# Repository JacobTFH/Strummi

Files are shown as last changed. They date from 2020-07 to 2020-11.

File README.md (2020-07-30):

# Strummi

## About

The _Strummi_ is a guitar-based Accessible Digital Musical Instrument (ADMI) designed to make guitar playing more physically accessible while preserving the tactile and acoustic response of real guitar strings.
It was developed as part of my PhD research at Queen Mary University of London, with my co-researcher Robert Jack.

The Strummi runs on c++ on the [Bela](https://bela.io/) environment.

You can see videos of the Strummi and find out more about it's use on the [projects](https://jacobtfh.github.io/projects) page of [my website](https://jacobtfh.github.io)

## To do

- Add source code and design files to git repo
- Design GUI in p5.js for changing tunings and chord voicings
- Make Instructables for DMLab AMIC
- Test with cycfi nu pickups
- Improvements to sound: body resonance / pickup modelling etc.

## License

<br />This work is licensed under a <a rel="license" href="http://creativecommons.org/licenses/by-nc/3.0/">Creative Commons Attribution-NonCommercial 3.0 Unported License</a>.

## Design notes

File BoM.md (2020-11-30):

*Enclosure:*
- 5mm plywood for lid and sides of enclosure
  - <2 sheets required
- 3mm plywood for base and binding
  - <1 sheet required
- 3mm acrylic for faceplate and connections panel
- 6x 30mm M3 hex spacers
- 12 x 30mm M3 bolts

*Strings*
- 6x zither pins
- Zither tuning key
- Guitar strings
  - 2x .40 gauge bass guitar string works well
- 6x string ferrules
- 4x cable crimps
- Felt for bridge

*Pickups*
- 6x 15mm piezo disc pickup
- 5mm and 3mm ply
  - use leftover from enclosure material
- 6mm foam plastazote
  - <1 sheet required

*Bela*
- Bela mini
- Custom PCB (see design files)
- 9-way male molex connector
- 12-way male molex connector
- 3-way male molex connector
- 3-way female header pins
- 10-way male header pin (long, for analog pins)
- ~16 male header pin (normal size, for digital pins)
  - we only need a few digital GPIO pins, so there's no need to populate the entire PCB. but it's useful to have a few extra for strain relief
- Bela audio connector (comes with Bela mini kit)
- Micro-USB to micro-USB panel mount connector

*Buttons*
- 2x 2x2 silicon push button pads
- 2x 2x2 push button PCB
- 6x M3 bolts
-

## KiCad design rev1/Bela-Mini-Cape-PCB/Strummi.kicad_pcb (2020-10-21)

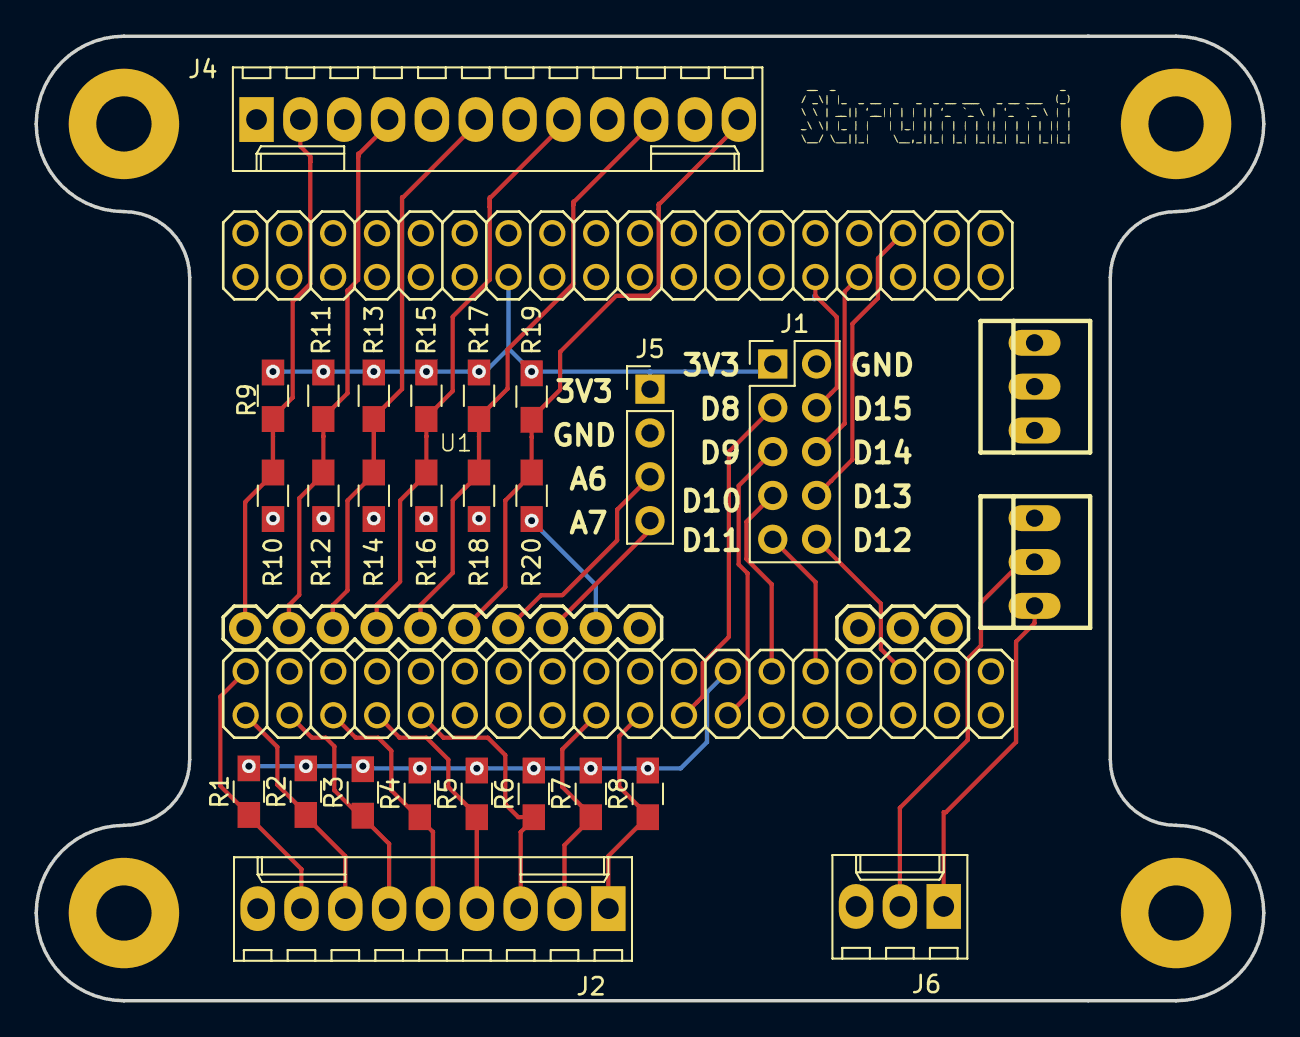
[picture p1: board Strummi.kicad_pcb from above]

Board: 2 copper layers, 71.1 x 55.9 mm, 26 parts (0 on the bottom side), 28 nets.

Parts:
J1: Conn_01x10_Female; Pin_Header_Straight_2x05_Pitch2.54mm
J2: Conn_01x09_Female; Molex_KK-6410-09_09x2.54mm_Straight
J4: Conn_01x12_Female; Molex_KK-6410-12_12x2.54mm_Straight
J5: Conn_01x04_Female; Pin_Header_Straight_1x04_Pitch2.54mm
J6: Conn_01x03_Female; Molex_KK-6410-03_03x2.54mm_Straight
R1, R2, R3, R4, R5, R6, R7, R8, R9, R10, R11, R12, R13, R14, R15, R16, R17, R18, R19, R20: R; R_0805_HandSoldering
U1: BelaMini_headers; BelaMini_headers_reverse

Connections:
+3V3: J1.1, J5.1, R1.2, R2.2, R3.2, R4.2, R5.2, R6.2, R7.2, R8.2, R9.2, R11.2, R13.2, R15.2, R17.2, R19.2, U1.P1_14, U1.P2_23
/A6: J5.3, U1.A6
/A7: J5.4, U1.A7
/Button0: J2.8, R1.1, U1.P2_01
/Button1: J2.7, R2.1, U1.P2_02
/Button2: J2.6, R3.1, U1.P2_04
/Button3: J2.5, R4.1, U1.P2_06
/Button4: J2.4, R5.1, U1.P2_08
/Button5: J2.3, R6.1, U1.P2_10
/Button6: J2.2, R7.1, U1.P2_18
/Button7: J2.1, R8.1, U1.P2_20
/D8: J1.3, U1.P2_22
/D9: J1.5, U1.P2_24
/D10: J1.7, U1.P2_25
/D11: J1.9, U1.P2_27
/D12: J1.10, U1.P2_31
/D13: J1.8, U1.P1_31
/D14: J1.6, U1.P1_30
/D15: J1.4, U1.P1_28
/Piezo0_B: J4.2, R9.1, R10.1, U1.A0
/Piezo1_B: J4.4, R11.1, R12.1, U1.A1
/Piezo2_B: J4.6, R13.1, R14.1, U1.A2
/Piezo3_B: J4.8, R15.1, R16.1, U1.A3
/Piezo4_B: J4.10, R17.1, R18.1, U1.A4
/Piezo5_B: J4.12, R19.1, R20.1, U1.A5
GNDA: J1.2, J2.9, J4.1, J4.3, J4.5, J4.7, J4.9, J4.11, J5.2, R10.2, R12.2, R14.2, R16.2, R18.2, R20.2, U1.A_GND
unnamed: J6.1, U1.Audio_Out_R
unnamed: J6.2, U1.Audio_Out_L

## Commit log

2020-07-30 - Updated readme - Added design files for laser cut enclosure
2020-10-21 Added kicad files for bela mini cape custom PCB
    [Strummi.kicad_pcb, Strummi.sch, StrummiCopper.kicad_pcb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]
2020-10-28 Changed folder structure.
    [Strummi.kicad_pcb, Strummi.sch, StrummiCopper.kicad_pcb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]
2020-11-12 Added gerbers.
    [Strummi-B_Cu.gbr, Strummi-B_Mask.gbr, Strummi-B_Paste.gbr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]
2020-11-16 Added drill file and zip of gerbers.
    [Strummi-NPTH.drl, Strummi-PTH.drl]
2020-11-18 updated with most recent enclosure design files
2020-11-18 Added design files for button PCB support and connections panel
2020-11-30 Create BoM.md
    updating bill of materials
